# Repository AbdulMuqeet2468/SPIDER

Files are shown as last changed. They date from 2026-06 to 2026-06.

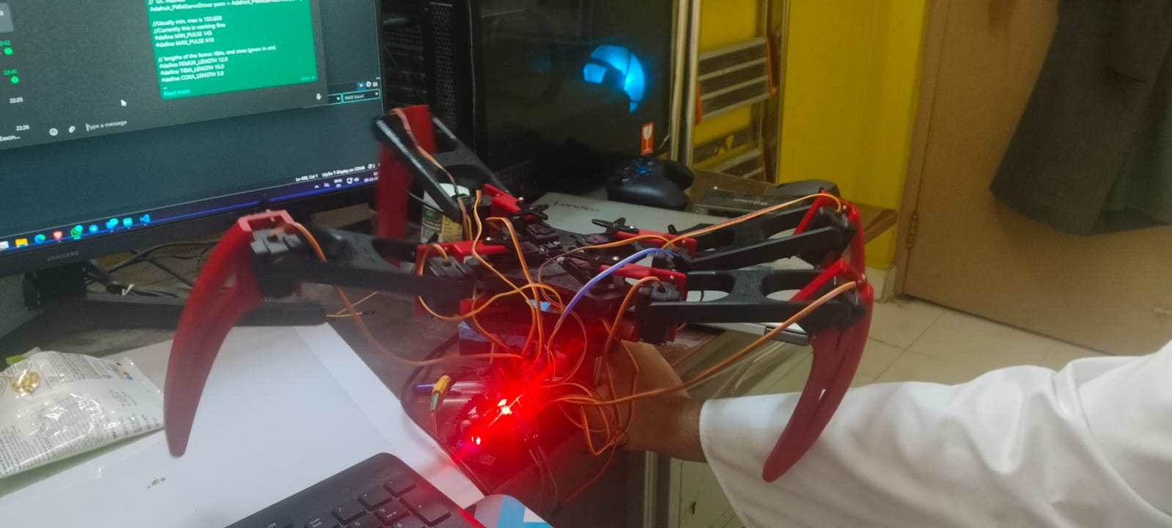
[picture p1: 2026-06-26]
Media/v2_test.jpeg

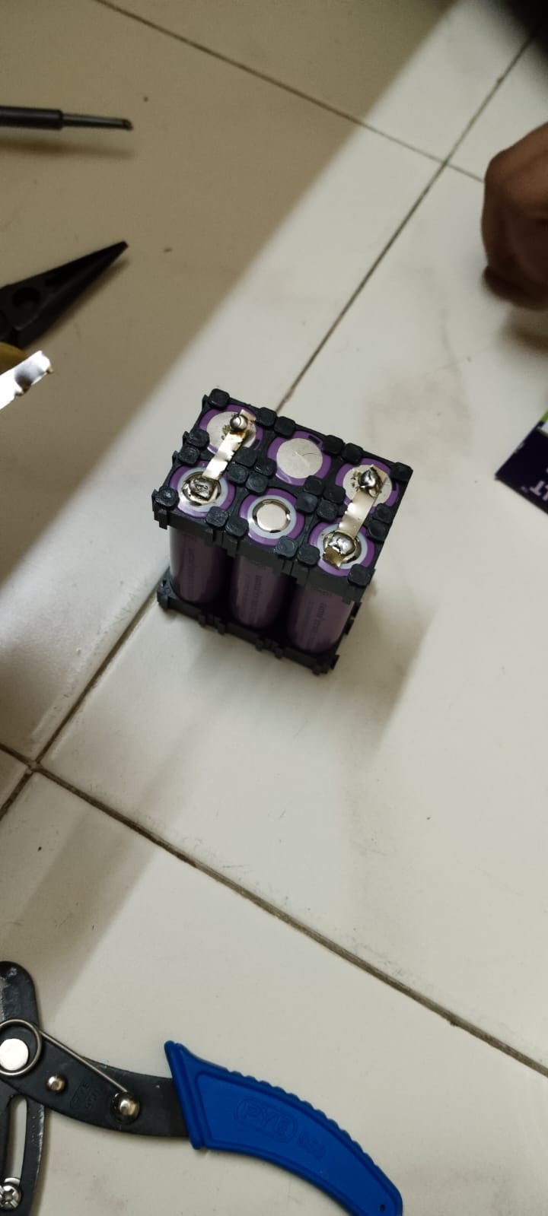
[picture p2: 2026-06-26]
Media/battery.jpeg

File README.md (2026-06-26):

# SPIDER
S.P.I.D.E.R (Smart Perceptive Intelligent Dual Environment Rover) is a four legged rover (each leg has 3 DOF) with both walking and wheel based traversing capabilities.

https://github.com/user-attachments/assets/5b39177c-7d02-429a-8edd-fe3f95df120c

https://github.com/user-attachments/assets/11dad433-c372-48c4-926b-07a860aa3b2b

Under progress:
1) IMU stabilization final verification
2) digital twin (GUI for control)
3) low level programming

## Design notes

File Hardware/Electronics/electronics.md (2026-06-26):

# Electronics Documentation

## Overview

This document covers the electronics design for SPIDER, including the power system, servo control, and microcontroller setup.

---

## Components

| Component | Specification | Purpose |
|---|---|---|
| Microcontroller | ESP32 | Main controller (Wi-Fi/BT capable) |
| PWM Driver | PCA9685 | 16-channel servo driver via I²C |
| Buck Converter | 10A, 300W | Steps down battery voltage to 5V for servos |
| Battery Pack | 2S3P Li-Ion | Main power source (~7.4V nominal) |
| BMS | 2S BMS | Cell protection & balancing |

---

## Power System

### Battery Pack — 2S3P Li-Ion

SPIDER is powered by a custom **2S3P Li-Ion battery pack**:

- **2S** → 2 cells in series → ~7.4V nominal, 8.4V fully charged
- **3P** → 3 cells in parallel per series group → higher capacity (3× a single cell)

#### How to Build a Custom Li-Ion Battery Pack

> ⚠️ **Warning:** Li-Ion cells can catch fire or explode if mishandled. Work carefully, avoid shorts, and never leave charging unattended.

**Materials needed:**
- 6× Li-Ion 18650 cells (matched capacity recommended)
- 2S BMS module (rated for your current draw)
- Nickel strips (0.15–0.2 mm thickness)
- Solder iron (spot welder recommended)
- Heat shrink tubing
- Kapton tape (recommended)
- Multimeter

**Steps:**

1. **Test all cells** — Measure each cell's voltage and internal resistance. Use only cells within ±0.05V of each other.

2. **Build the parallel groups (P groups)** — Place 3 cells side-by-side (same orientation). Solder nickel strips across the positive ends and negative ends to connect them in parallel. You now have two 3P groups.

3. **Connect groups in series (S)** — Connect the negative terminal of one 3P group to the positive terminal of the other using a nickel strip. This gives you 2S3P.

4. **Attach the BMS** — Wire the BMS according to its datasheet:
   - `B-` → pack negative
   - `B1` (balance tap) → midpoint between the two groups
   - `B+` → pack positive
   - `P-` and `P+` → output terminals

5. **Insulate & wrap** — Apply Kapton tape between cells to prevent shorts. Slide heat shrink tubing over the entire pack and shrink with a heat gun.

6. **Verify output** — Measure voltage at the output terminals. Should read ~7.4–8.4V.

---

### 2S BMS

The BMS (Battery Management System) provides:
- **Overcurrent protection**
- **Overcharge / over-discharge protection**
- **Cell balancing** between the two series groups

Select a BMS rated for at least the peak current draw of your robot.

---

### Buck Converter (10A, 300W)

Servos typically require **5V**, but the 2S battery outputs ~7.4–8.4V. The buck converter steps this down.

**Wiring:**
```
Battery (+) ──► Buck IN+
Battery (-) ──► Buck IN-
Buck OUT+ ──► 5V Rail (PCA9685 VCC + Servo power)
Buck OUT- ──► GND Rail
```

**Setup:**
- Adjust the output trim potentiometer to exactly **5.0V** before connecting servos.
- Ensure the converter is rated beyond your total servo stall current (sum of all servos × stall current).

---

## Servo Control

### PCA9685 PWM Driver

The **PCA9685** is a 16-channel PWM driver communicating over **I²C**, allowing the ESP32 to control all leg servos with just 2 GPIO pins.

**Wiring to ESP32:**

| PCA9685 Pin | ESP32 Pin |
|---|---|
| VCC | 3.3V |
| GND | GND |
| SDA | GPIO 21 |
| SCL | GPIO 22 |
| V+ | 5V Rail (from buck converter) |

> The `V+` pin powers the servo motors directly — connect it to the 5V output of the buck converter, **not** the ESP32's 3.3V or 5V pin.

## Safety Notes

- Always **power down** before rewiring.
- Never bypass the BMS output for servo power.
- Add a **main fuse** (10–15A) between the battery and the rest of the circuit.
- Use adequately rated wires for the high-current servo rail (18–20 AWG minimum).

**Note**
We removed DC motor feature, thats why it is not mentioned in the documentation

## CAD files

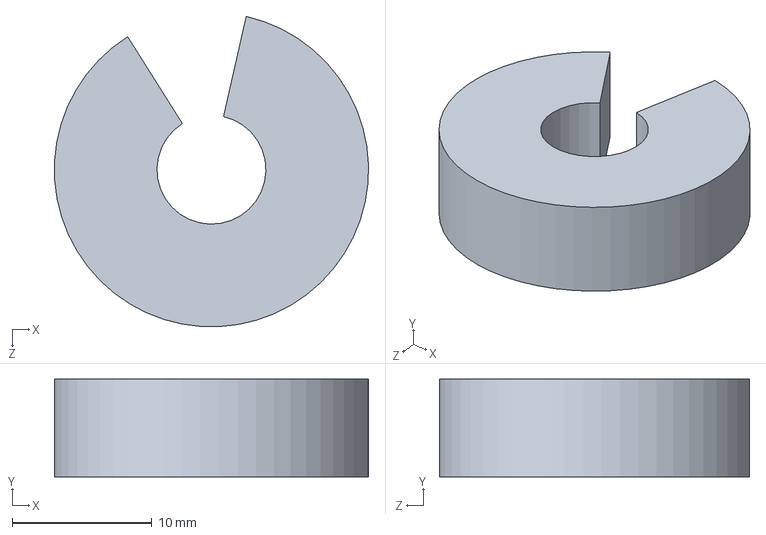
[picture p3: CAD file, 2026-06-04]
Hardware/CAD Models/SPIDER v2/Solidworks prt files/print bearing.SLDPRT
22.5 x 7.00 x 22.2 mm

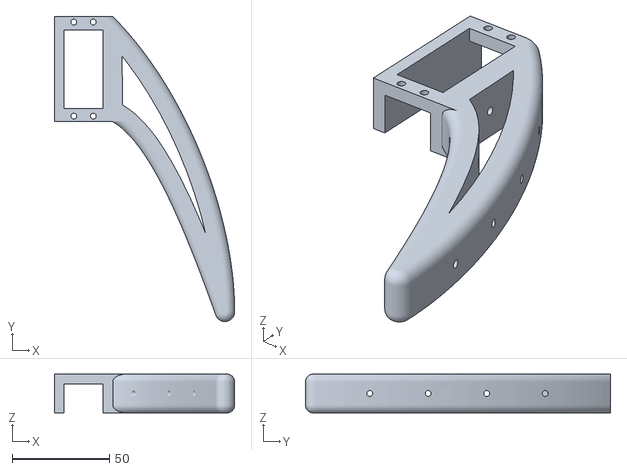
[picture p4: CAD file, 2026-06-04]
Hardware/CAD Models/SPIDER v2/stll files/tibia right.STL
92.5 x 156.6 x 20.0

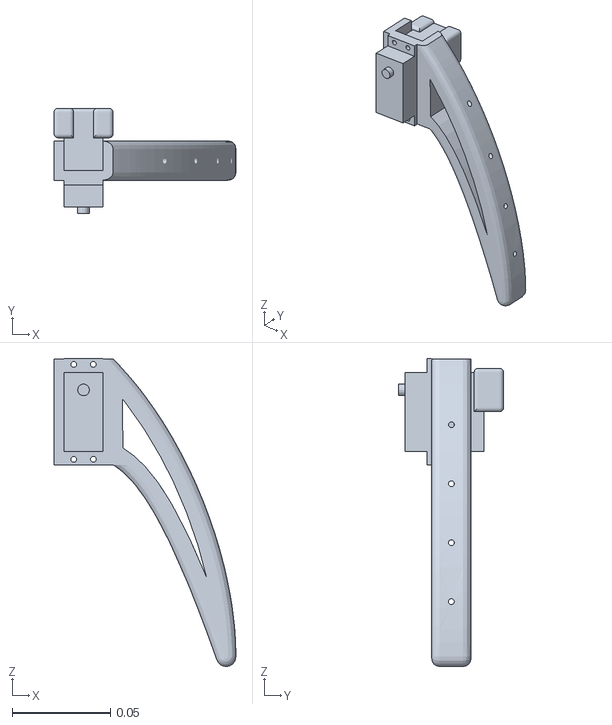
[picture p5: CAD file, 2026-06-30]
Software/Simulations/FullAsm/meshes/L1_tibia_link.STL
0.0925 x 0.0536 x 0.157

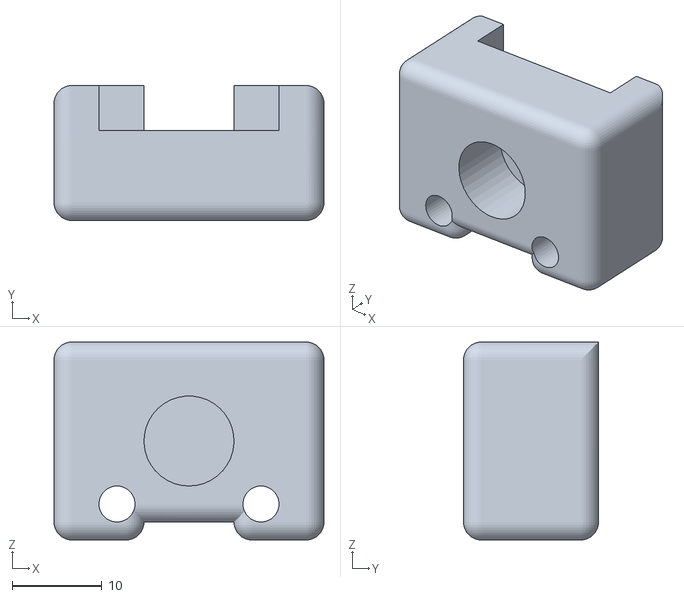
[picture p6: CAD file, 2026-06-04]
Hardware/CAD Models/SPIDER v2/stll files/servo connector_n.STL
30.0 x 15.0 x 22.0

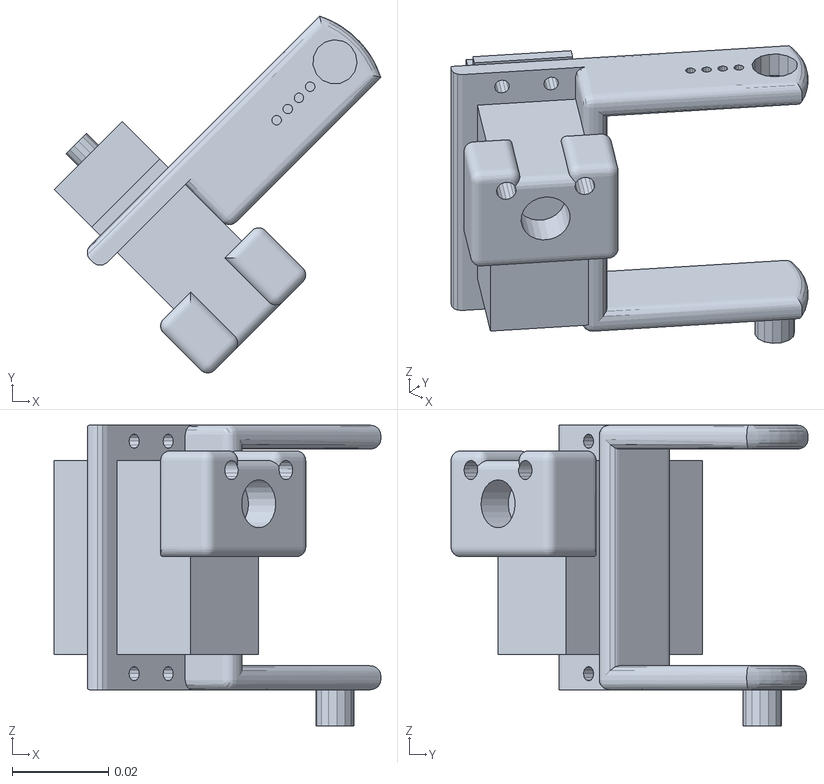
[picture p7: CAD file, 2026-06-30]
Software/Simulations/FullAsm/meshes/L2_coxa_link.STL
0.0679 x 0.0742 x 0.0625

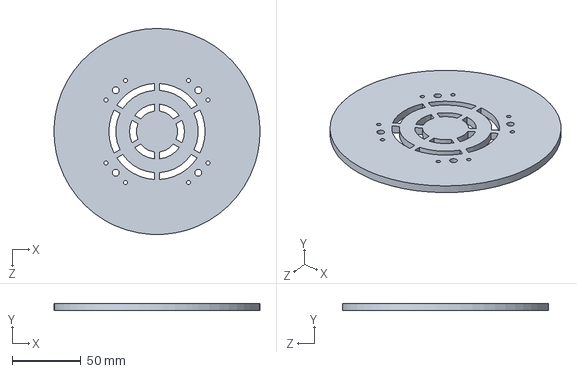
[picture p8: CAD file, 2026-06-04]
Hardware/CAD Models/SPIDER v2/Solidworks prt files/plate.SLDPRT
149.9 x 5.00 x 150.0 mm

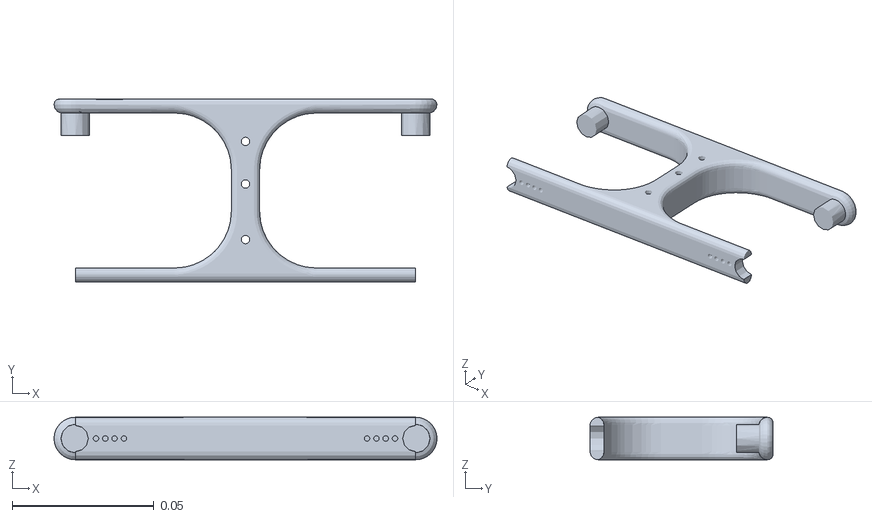
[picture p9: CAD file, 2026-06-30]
Software/Simulations/FullAsm/meshes/L2_femur_link.STL
0.135 x 0.0646 x 0.015

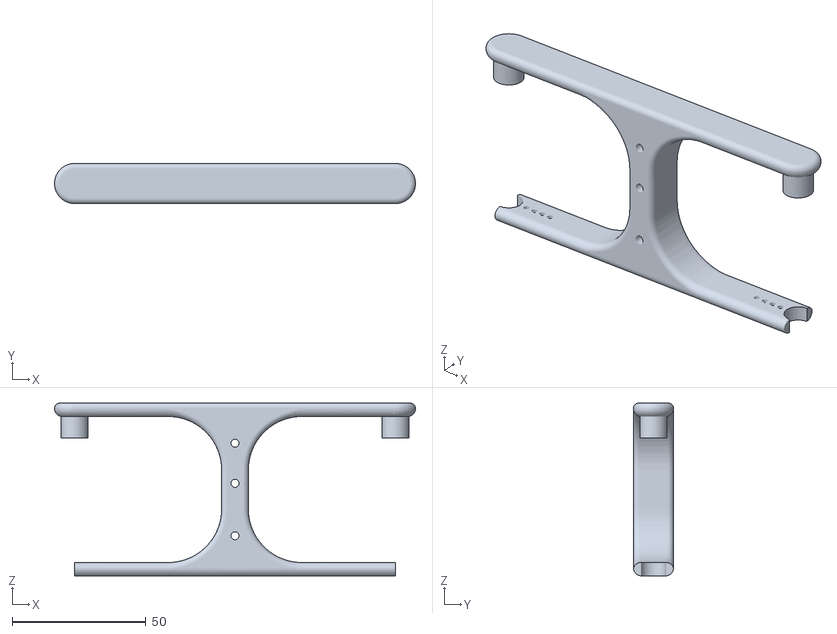
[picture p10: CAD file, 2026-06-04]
Hardware/CAD Models/SPIDER v2/stll files/femur_n.STL
134.9 x 15.0 x 64.6

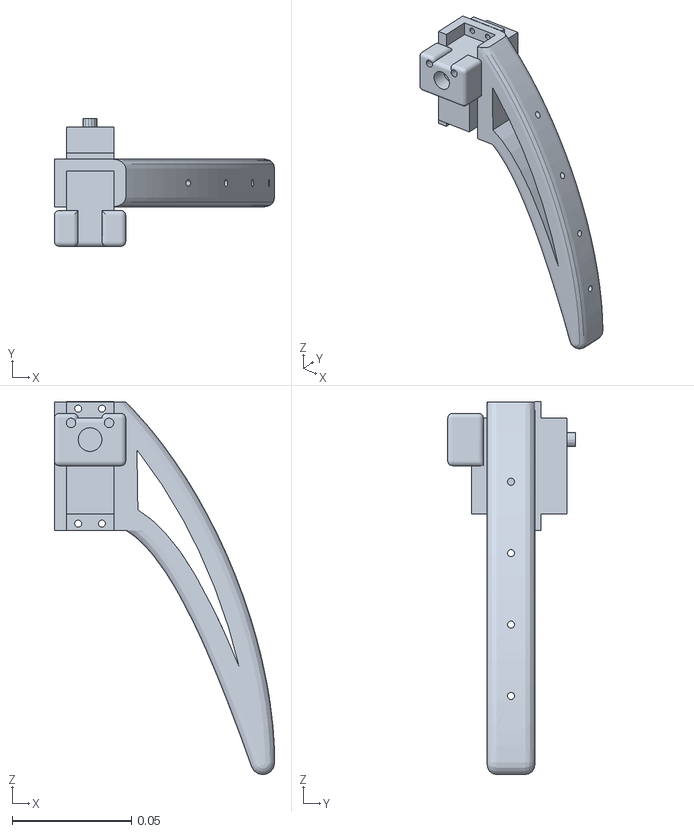
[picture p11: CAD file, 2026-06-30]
Software/Simulations/FullAsm/meshes/R2_tibia_link.STL
0.0925 x 0.0536 x 0.157

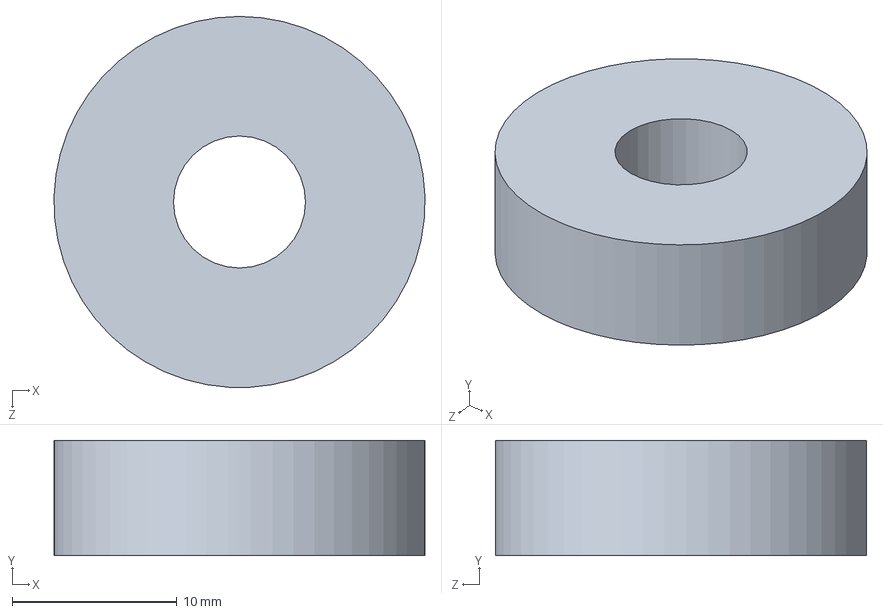
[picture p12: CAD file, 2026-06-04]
Hardware/CAD Models/SPIDER v2/Solidworks prt files/bearing.SLDPRT
22.5 x 7.00 x 22.5 mm

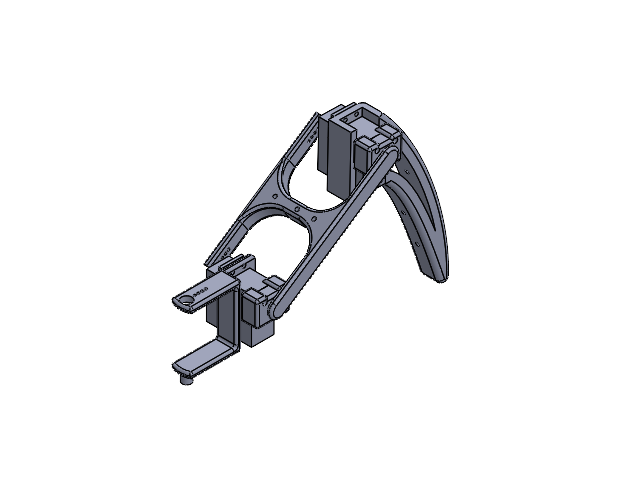
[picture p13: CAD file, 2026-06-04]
Hardware/CAD Models/SPIDER v2/Assembly files/leg1.SLDASM
coxa connector left
servo motor x 2
servo connector x 2
femur
tibia left

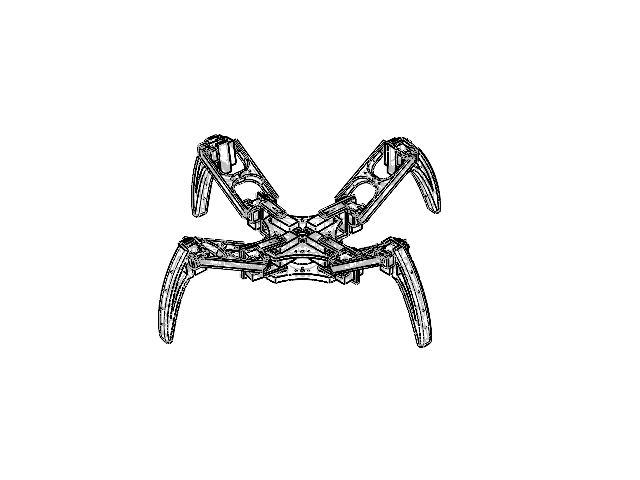
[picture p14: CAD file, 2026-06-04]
Hardware/CAD Models/SPIDER v2/Assembly files/assembly 1.SLDASM
top plate
servo motor x 12
base plate
bearing x 4
coxa connector left x 2
servo connector x 8
femur x 4
tibia left x 2
coxa connector right x 2
tibia x 2

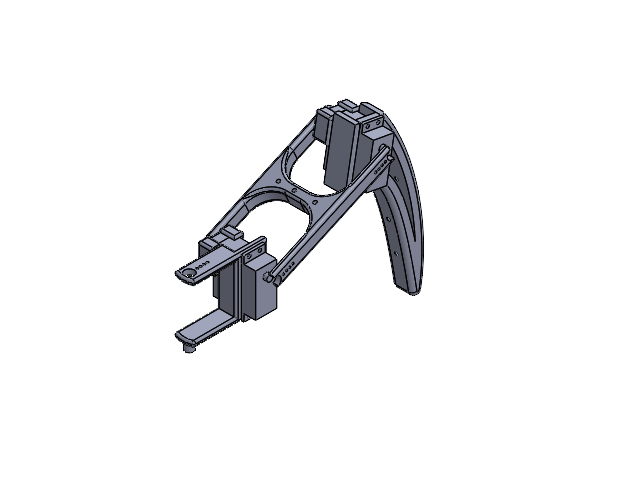
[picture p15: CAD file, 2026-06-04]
Hardware/CAD Models/SPIDER v2/Assembly files/leg 2.SLDASM
coxa connector right
servo motor x 2
servo connector x 2
femur
tibia

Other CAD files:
Hardware/CAD Models/SPIDER v2/Solidworks prt files/tibia.SLDPRT
Hardware/CAD Models/SPIDER v2/stll files/tibia left.STL
Hardware/CAD Models/SPIDER v2/Solidworks prt files/tibia left.SLDPRT
Hardware/CAD Models/SPIDER v2/stll files/print bearing_n.STL
Software/Simulations/FullAsm/meshes/R1_femur_link.STL
Hardware/CAD Models/SPIDER v1/Assembly Files/MG996R Servo Motor.SLDASM
Hardware/CAD Models/SPIDER v1/Assembly Files/final_assembly.SLDASM
Hardware/CAD Models/SPIDER v1/Part Files/2nd_slab.SLDPRT
Hardware/CAD Models/SPIDER v1/Part Files/Case.SLDPRT
Hardware/CAD Models/SPIDER v1/Part Files/FINAL_JOINT.SLDPRT
Hardware/CAD Models/SPIDER v1/Part Files/Output Shaft.SLDPRT
Hardware/CAD Models/SPIDER v1/Part Files/Pan Head Cross Screw M1.6.SLDPRT
Hardware/CAD Models/SPIDER v1/Part Files/Rubber Wire Cable Sleeve.SLDPRT
Hardware/CAD Models/SPIDER v1/Part Files/base_first.SLDPRT
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

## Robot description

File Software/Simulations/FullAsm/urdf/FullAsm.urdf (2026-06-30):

<?xml version="1.0" encoding="utf-8"?>
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
<robot name="FullAsm">
  <link name="base_link">
    <inertial>
      <origin xyz="1.41553435639707E-15 -4.71844785465692E-16 0.0288056562241538" rpy="0 0 0" />
      <mass value="0.264155966188661" />
      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
    </inertial>
    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
  </link>
  <link name="R1_coxa_Link">
    <inertial>
      <origin xyz="0.0319537213335016 0.0310974587430851 0.0359048445285311" rpy="0 0 0" />
      <mass value="0.0539542934009624" />
      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
    </inertial>
    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
  </link>
  <joint name="R1_coxa_joint" type="revolute">
    <origin xyz="0.035355 0.035355 0.0025" rpy="0 0 0" />
    <parent link="base_link" />
    <child link="R1_coxa_Link" />
    <axis xyz="0 0 -1" />
    <limit lower="-1.57" upper="1.57" effort="1" velocity="5" />
  </joint>
  <link name="R1_femur_link">
    <inertial>
      <origin xyz="0.0600000067722221 0.0169799829054785 2.74393535670825E-09" rpy="0 0 0" />
      <mass value="0.0310992117923054" />
      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
    </inertial>
    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
  </link>
  <joint name="R1_femur_joint" type="revolute">
    <origin xyz="0.049215 0.021496 0.04615" rpy="0 0 0.7854" />
    <parent link="R1_coxa_Link" />
    <child link="R1_femur_link" />
    <axis xyz="0 1 0" />
    <limit lower="-1.57" upper="1.57" effort="1" velocity="5" />
  </joint>
  <link name="R1_tibia_link">
    <inertial>
      <origin xyz="0.00655839970820876 0.0169182504471019 -0.0341878336261486" rpy="0 0 0" />
      <mass value="0.102493419295609" />
      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
    </inertial>
    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
  </link>
  <joint name="R1_tibia_joint" type="revolute">
    <origin xyz="0.12 0 0" rpy="0 0 0" />
    <parent link="R1_femur_link" />
    <child link="R1_tibia_link" />
    <axis xyz="0 1 0" />
    <limit lower="-1.57" upper="1.57" effort="1" velocity="5" />
  </joint>
  <link name="R2_coxa_link">
    <inertial>
      <origin xyz="0.0310974587430911 -0.0319537213334928 0.0359048445285313" rpy="0 0 0" />
      <mass value="0.0539542934009624" />
      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
    </inertial>
    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
  </link>
  <joint name="R2_coxa_joint" type="revolute">
    <origin xyz="0.035355 -0.035355 0.0025" rpy="0 0 0" />
    <parent link="base_link" />
    <child link="R2_coxa_link" />
    <axis xyz="0 0 -1" />
    <limit lower="-1.57" upper="1.57" effort="1" velocity="5" />
  </joint>
  <link name="R2_femur_link">
    <inertial>
      <origin xyz="0.0599999932277789 0.016979982905482 -2.74393624488667E-09" rpy="0 0 0" />
      <mass value="0.0310992117923055" />
      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
    </inertial>
    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
  </link>
  <joint name="R2_femur_joint" type="revolute">
    <origin xyz="0.021496 -0.049215 0.04615" rpy="0 0 -0.7854" />
    <parent link="R2_coxa_link" />
    <child link="R2_femur_link" />
    <axis xyz="0 1 0" />
    <limit lower="-1.57" upper="1.57" effort="1" velocity="5" />
  </joint>
  <link name="R2_tibia_link">
    <inertial>
      <origin xyz="0.0243017082939564 0.0185913598036986 -0.0370672669441691" rpy="0 0 0" />
      <mass value="0.104443081837186" />
      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
    </inertial>
    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
  </link>
  <joint name="R2_tibia_joint" type="revolute">
    <origin xyz="0.12 0 0" rpy="0 0 0" />
    <parent link="R2_femur_link" />
    <child link="R2_tibia_link" />
    <axis xyz="0 1 0" />
    <limit lower="-1.57" upper="1.57" effort="1" velocity="5" />
  </joint>
  <link name="L1_coxa_link">
    <inertial>
      <origin xyz="-0.0319497690555947 0.0310935472043496 0.0359057644094145" rpy="0 0 0" />
      <mass value="0.0539261316374727" />
      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
    </inertial>
    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
  </link>
  <joint name="L1_coxa_joint" type="revolute">
    <origin xyz="-0.035355 0.035355 0.0025" rpy="0 0 0" />
    <parent link="base_link" />
    <child link="L1_coxa_link" />
    <axis xyz="0 0 -1" />
    <limit lower="-1.57" upper="1.57" effort="1" velocity="5" />
  </joint>
  <link name="L1_femur_link">
    <inertial>
      <origin xyz="0.0600000067722205 -0.0169799829054843 -2.74393627264224E-09" rpy="0 0 0" />
      <mass value="0.0310992117923055" />
      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
    </inertial>
    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
  </link>
  <joint name="L1_femur_joint" type="revolute">
    <origin xyz="-0.049215 0.021496 0.04615" rpy="0 0 2.3562" />
    <parent link="L1_coxa_link" />
    <child link="L1_femur_link" />
    <axis xyz="0 -1 0" />
    <limit lower="-1.57" upper="1.57" effort="1" velocity="5" />
  </joint>
  <link name="L1_tibia_link">
    <inertial>
      <origin xyz="0.0243017574568316 -0.0185912905496515 -0.0370679121812122" rpy="0 0 0" />
      <mass value="0.10444112998834" />
      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
    </inertial>
    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
  </link>
  <joint name="L1_tibia_joint" type="revolute">
    <origin xyz="0.12 0 0" rpy="0 0 0" />
    <parent link="L1_femur_link" />
    <child link="L1_tibia_link" />
    <axis xyz="0 -1 0" />
    <limit lower="-1.57" upper="1.57" effort="1" velocity="5" />
  </joint>
  <link name="L2_coxa_link">
    <inertial>
      <origin xyz="-0.0310935471472172 -0.0319497691637255 0.0359057645758147" rpy="0 0 0" />
      <mass value="0.0539261320763142" />
      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
    </inertial>
    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
  </link>
  <joint name="L2_coxa_joint" type="revolute">
    <origin xyz="-0.035355 -0.035355 0.0025" rpy="0 0 0" />
    <parent link="base_link" />
    <child link="L2_coxa_link" />
    <axis xyz="0 0 -1" />
    <limit lower="-1.57" upper="1.57" effort="1" velocity="5" />
  </joint>
  <link name="L2_femur_link">
    <inertial>
      <origin xyz="0.0600000067722211 -0.0169799829054821 -2.74393503751913E-09" rpy="0 0 0" />
      <mass value="0.0310992117923054" />
      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
    </inertial>
    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
  </link>
  <joint name="L2_femur_joint" type="revolute">
    <origin xyz="-0.021496 -0.049215 0.04615" rpy="0 0 -2.3562" />
    <parent link="L2_coxa_link" />
    <child link="L2_femur_link" />
    <axis xyz="0 -1 0" />
    <limit lower="-1.57" upper="1.57" effort="1" velocity="5" />
  </joint>
  <link name="L2_tibia_link">
    <inertial>
      <origin xyz="0.0243017574568304 -0.0185912905496581 -0.037067912181212" rpy="0 0 0" />
      <mass value="0.10444112998834" />
      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
    </inertial>
    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
  </link>
  <joint name="L2_tibia_joint" type="revolute">
    <origin xyz="0.12 0 0" rpy="0 0 0" />
    <parent link="L2_femur_link" />
    <child link="L2_tibia_link" />
    <axis xyz="0 -1 0" />
    <limit lower="-1.57" upper="1.57" effort="1" velocity="5" />
  </joint>
</robot>

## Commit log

2025-05-26 Inverse Kinematics Static test
2025-05-27 Basis of battery: types discussed
2026-06-04 Add CAD versions
    [2nd_slab.SLDPRT, Case.SLDPRT, FINAL_JOINT.SLDPRT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]
2026-06-30 coppeliasim individual joint controller
2026-06-30 URDF folder
    [FullAsm.csv, FullAsm.urdf, L1_coxa_link.STL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]
